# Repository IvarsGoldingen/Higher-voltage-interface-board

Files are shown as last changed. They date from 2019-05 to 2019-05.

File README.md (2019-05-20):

# Higher voltage interface board

The device can be used to interface higher voltage DC systems. This specific device is intended for 24VDC.

## Features

* 4 high side transistor outputs;
* 6 inputs using voltage dividers;
* 4 relay outputs;
* 2 buttons;
* 1 LED;
* EEPROM via SPI;
* 2 seperate 5V power inputs: one for relays, the other for other components. Can be jumped together.

## Photos




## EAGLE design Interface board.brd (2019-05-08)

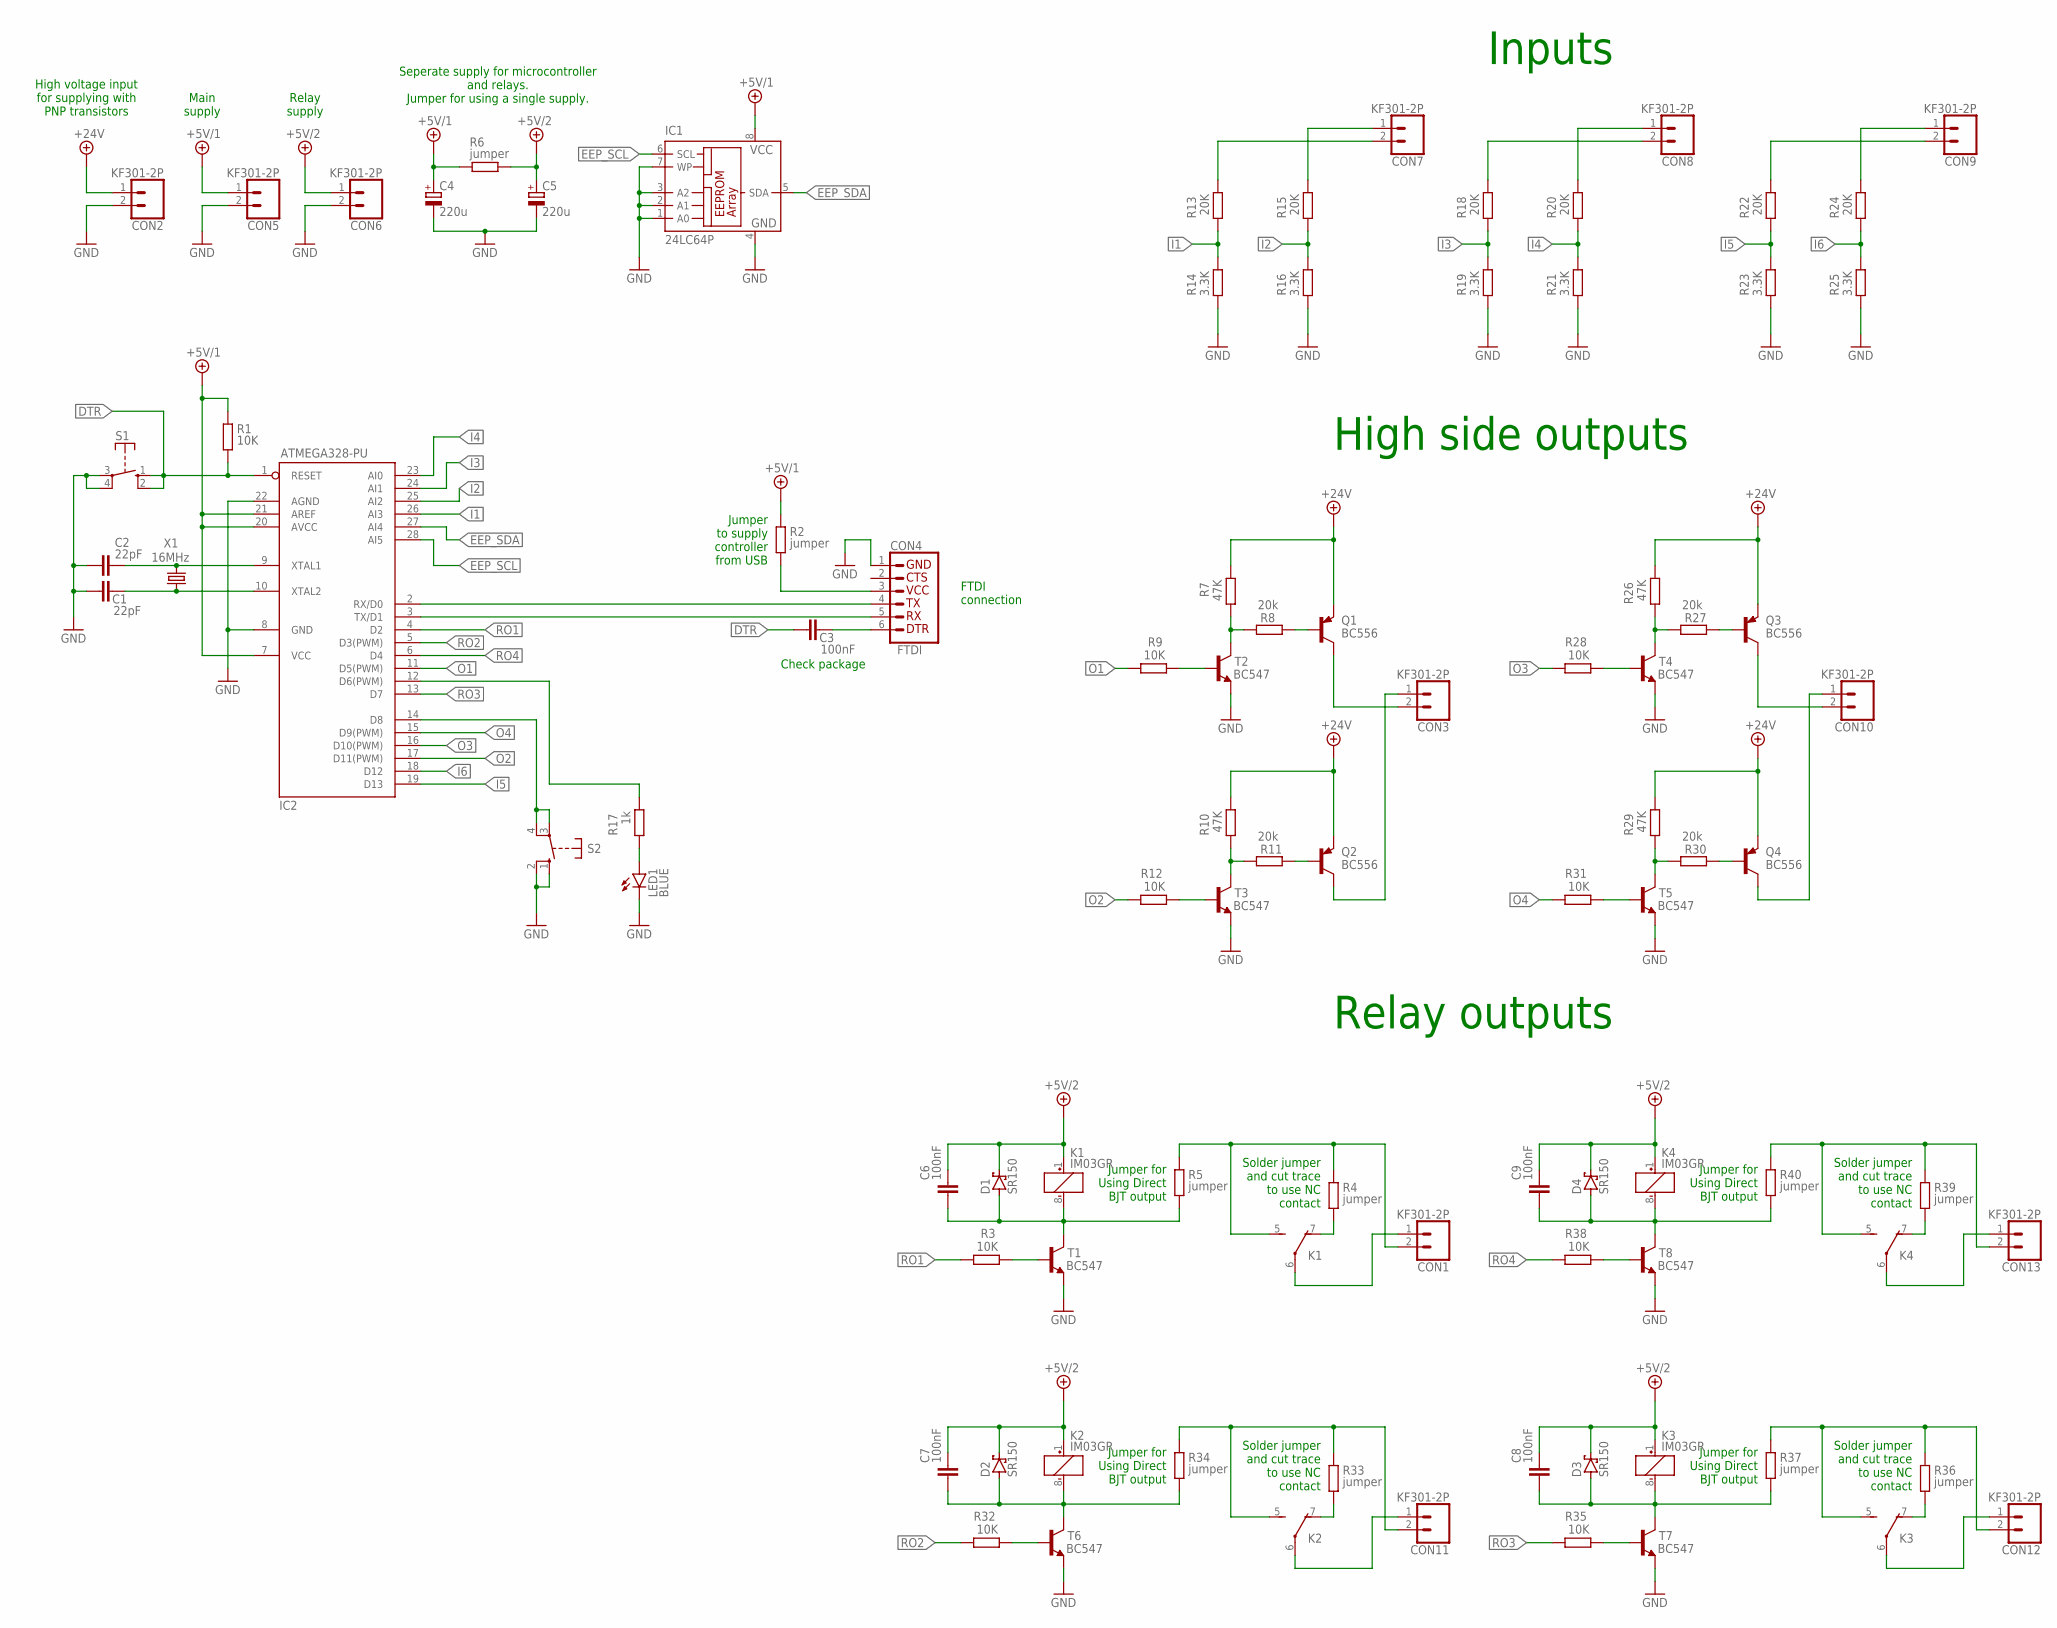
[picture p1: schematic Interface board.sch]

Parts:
C1, C2: 22pF; C050-024X044
C3, C6, C7, C8, C9: 100nF; C050-024X044
C4, C5: 220u; E5-10,5
CON1, CON2, CON3, CON5, CON6, CON7, CON8, CON9, CON10, CON11, CON12, CON13: KF301-2P
CON4: FTDI; 1X06_W_REC_GND
D1, D2, D3, D4: SR150; DO41-7.6
IC1: 24LC64P; DIL8
IC2: ATMEGA328-PU; DIL28-3
K1, K2, K3, K4: IM03GR
LED1: BLUE; LED5MM
Q1, Q2, Q3, Q4: BC556; TO92-EBC
R1, R3, R9, R12, R28, R31, R32, R35, R38: 10K; 0204/7
R2, R4, R5, R6, R33, R34, R36, R37, R39, R40: jumper; R0805
R7, R10, R26, R29: 47K; 0204/7
R8, R11, R27, R30: 20k; 0204/7
R13, R15, R18, R20, R22, R24: 20K; 0204/7
R14, R16, R19, R21, R23, R25: 3.3K; 0204/7
R17: 1k; 0204/7
S1, S2: RACON12
T1, T2, T3, T4, T5, T6, T7, T8: BC547; TO92
X1: 16MHz; HC49

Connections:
+5V/1: C4.+, CON5.1, IC1.8 (VCC), IC2.7 (VCC), IC2.20 (AVCC), IC2.21 (AREF), R1.1, R2.1, R6.1
+5V/2: C5.+, C6.1, C7.1, C8.1, C9.1, CON6.1, D1.C, D2.C, D3.C, D4.C, K1.1 (+), K2.1 (+), K3.1 (+), K4.1 (+), R6.2
+24V: CON2.1, Q1.E, Q2.E, Q3.E, Q4.E, R7.2, R10.2, R26.2, R29.2
DTR: C3.2, IC2.1 (RESET), R1.2, S1.1 (S), S1.2 (S)
EEP_SCL: IC1.6 (SCL), IC2.28 (AI5)
EEP_SDA: IC1.5 (SDA), IC2.27 (AI4)
GND: C1.2, C2.2, C4.-, C5.-, CON2.2, CON4.1 (6), CON5.2, CON6.2, IC1.1 (A0), IC1.2 (A1), IC1.3 (A2), IC1.4 (GND), IC1.7 (WP), IC2.8 (GND), IC2.22 (AGND), LED1.K (C), R14.1, R16.1, R19.1, R21.1, R23.1, R25.1, S1.3, S1.4, S2.1 (S), S2.2 (S), T1.1 (E), T2.1 (E), T3.1 (E), T4.1 (E), T5.1 (E), T6.1 (E), T7.1 (E), T8.1 (E)
I1: IC2.26 (AI3), R13.1, R14.2
I2: IC2.25 (AI2), R15.1, R16.2
I3: IC2.24 (AI1), R18.1, R19.2
I4: IC2.23 (AI0), R20.1, R21.2
I5: IC2.19 (D13), R22.1, R23.2
I6: IC2.18 (D12), R24.1, R25.2
unnamed: C1.1, IC2.10 (XTAL2), X1.2
unnamed: C2.1, IC2.9 (XTAL1), X1.1
unnamed: IC2.12 (D6(PWM)), R17.2
unnamed: CON4.4 (3), IC2.2 (RX/D0)
unnamed: CON4.5 (2), IC2.3 (TX/D1)
unnamed: C3.1, CON4.6 (1)
unnamed: IC2.14 (D8), S2.3, S2.4
unnamed: CON4.3 (4), R2.2
unnamed: R3.2, T1.2 (B)
unnamed: R9.2, T2.2 (B)
unnamed: CON1.1, K1.6
unnamed: K1.7 (O), R4.2
unnamed: CON1.2, K1.5 (S), R4.1, R5.1
unnamed: R38.2, T8.2 (B)
unnamed: R7.1, R8.2, T2.3 (C)
unnamed: Q1.B, R8.1
unnamed: C6.2, D1.A, K1.8 (-), R5.2, T1.3 (C)
unnamed: R10.1, R11.2, T3.3 (C)
unnamed: Q2.B, R11.1
unnamed: R12.2, T3.2 (B)
unnamed: CON3.2, Q1.C
unnamed: CON3.1, Q2.C
unnamed: R32.2, T6.2 (B)
unnamed: CON11.1, K2.6
unnamed: CON13.1, K4.6
unnamed: CON7.2, R13.2
unnamed: CON13.2, K4.5 (S), R39.1, R40.1
unnamed: CON7.1, R15.2
unnamed: LED1.A, R17.1
unnamed: CON9.2, R22.2
unnamed: CON8.2, R18.2
unnamed: CON9.1, R24.2
unnamed: CON8.1, R20.2
unnamed: R26.1, R27.2, T4.3 (C)
unnamed: Q3.B, R27.1
unnamed: K4.7 (O), R39.2
unnamed: CON11.2, K2.5 (S), R33.1, R34.1
unnamed: K2.7 (O), R33.2
unnamed: C9.2, D4.A, K4.8 (-), R40.2, T8.3 (C)
unnamed: C7.2, D2.A, K2.8 (-), R34.2, T6.3 (C)
unnamed: R28.2, T4.2 (B)
unnamed: R29.1, R30.2, T5.3 (C)
unnamed: Q4.B, R30.1
unnamed: R31.2, T5.2 (B)
unnamed: CON10.2, Q3.C
unnamed: CON10.1, Q4.C
unnamed: R35.2, T7.2 (B)
unnamed: CON12.1, K3.6
unnamed: CON12.2, K3.5 (S), R36.1, R37.1
unnamed: K3.7 (O), R36.2
unnamed: C8.2, D3.A, K3.8 (-), R37.2, T7.3 (C)
O1: IC2.11 (D5(PWM)), R9.1
O2: IC2.17 (D11(PWM)), R12.1
O3: IC2.16 (D10(PWM)), R28.1
O4: IC2.15 (D9(PWM)), R31.1
RO1: IC2.4 (D2), R3.1
RO2: IC2.5 (D3(PWM)), R32.1
RO3: IC2.13 (D7), R35.1
RO4: IC2.6 (D4), R38.1

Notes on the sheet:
FTDI connection
Check package
Jumper to supply controller from USB
Solder jumper and cut trace to use NC contact
Jumper for Using Direct BJT output
Seperate supply for microcontroller and relays. Jumper for using a single supply.
High voltage input for supplying with PNP transistors
Main supply
Relay supply
Inputs
High side outputs
Relay outputs

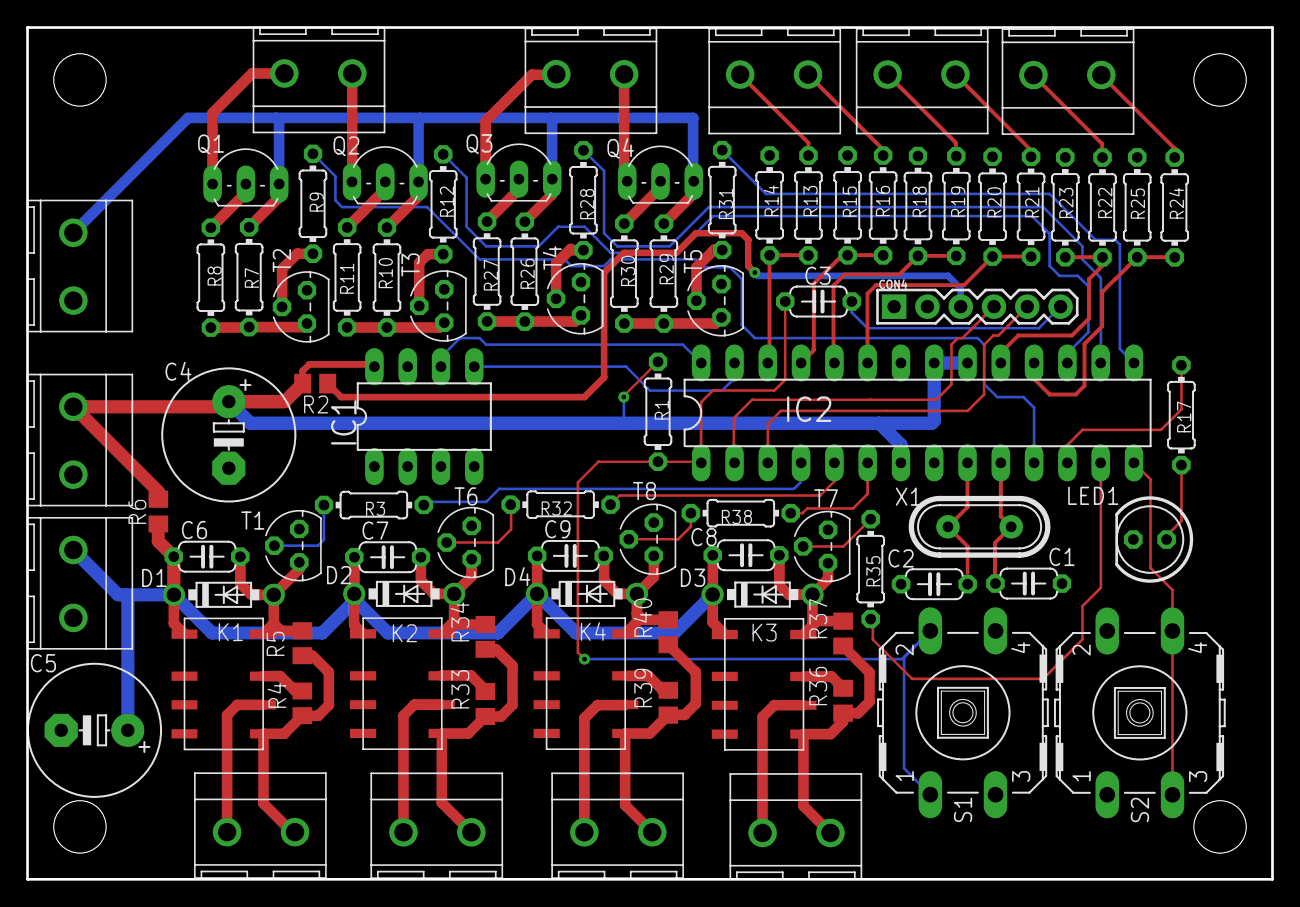
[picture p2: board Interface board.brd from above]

Board: 2 copper layers, 95.0 x 65.0 mm, 88 parts (0 on the bottom side), 72 nets.

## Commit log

2019-05-08 First version
    First version of interface board
    [Interface board.brd, Interface board.sch]
2019-05-20 Update README.md
    Picture of soldered PCB added
